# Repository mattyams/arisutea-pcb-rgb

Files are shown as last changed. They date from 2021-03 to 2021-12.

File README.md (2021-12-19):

- [X] Edit QMK firmware for v0.4 Arisutea RGB design (07-07-21)
- [X] v0.4 Arisutea RGB PCBs ordered (07-26-21)
- [X] Assemble v0.4 Arisutea RGB PCB once received (11-21-21)
- [X] Assemble Acrylic Case to v0.4 Arisutea RGB design (11-21-21)

## Arisutea RGB Underglow - Arisu Keyboard PCB with More Modifications...now with MORE!

### Disclaimer: Use these files at your own risk!

アリステア PCB designed using KiCad. The layout was originally created by FateNozomi, inspired by Lyn's EM7 and TGR Alice with some modification. The layout was then modified by CorruptedJef and robotictomato to add USB-C, ESD and to shift/add some keys. This inspired me to modify the layout further by adding the ability to swap your switches out whenever you want, make some keys a little more permenant and add some underglow around the edges. If you notice any issue please open an issue and we can discuss!

Since the layout has been modified yet again I decided to give the project a new name, Arisutea, which translates to Alistair. Obviously keeping the theme running here. 

Check out the iBOM [here](https://htmlpreview.github.io/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)! This was generated with [InteractiveHtmlBom](https://github.com/openscopeproject/InteractiveHtmlBom)!

Key modifications to the PCB:

- Added in Kailh Hotswap sockets.
- Addition of full backspace position, connected to switch 59 (row 0, column 13).
  - Removed switch 63 and repositioned switch 59 to add full backspace position.
- USB-C ESD rework.
- Added 21 SK6812Mini-E underglow LEDs around the edge.
- Added LED indicators for CAPS and NUM lock as well as layer.
- Updated JSON layout file for this particular keyboard.

Renders generated by [Tracespace](https://github.com/tracespace/tracespace).
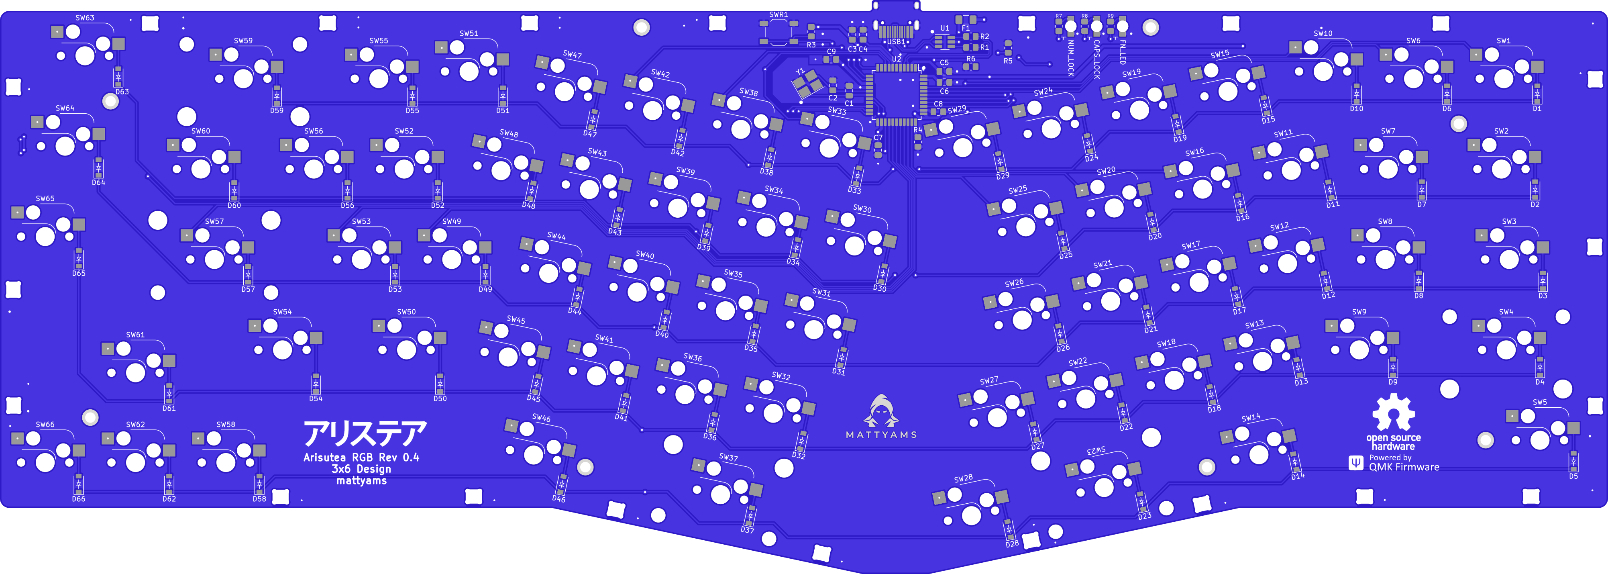
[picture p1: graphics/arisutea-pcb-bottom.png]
Arisutea-RGB

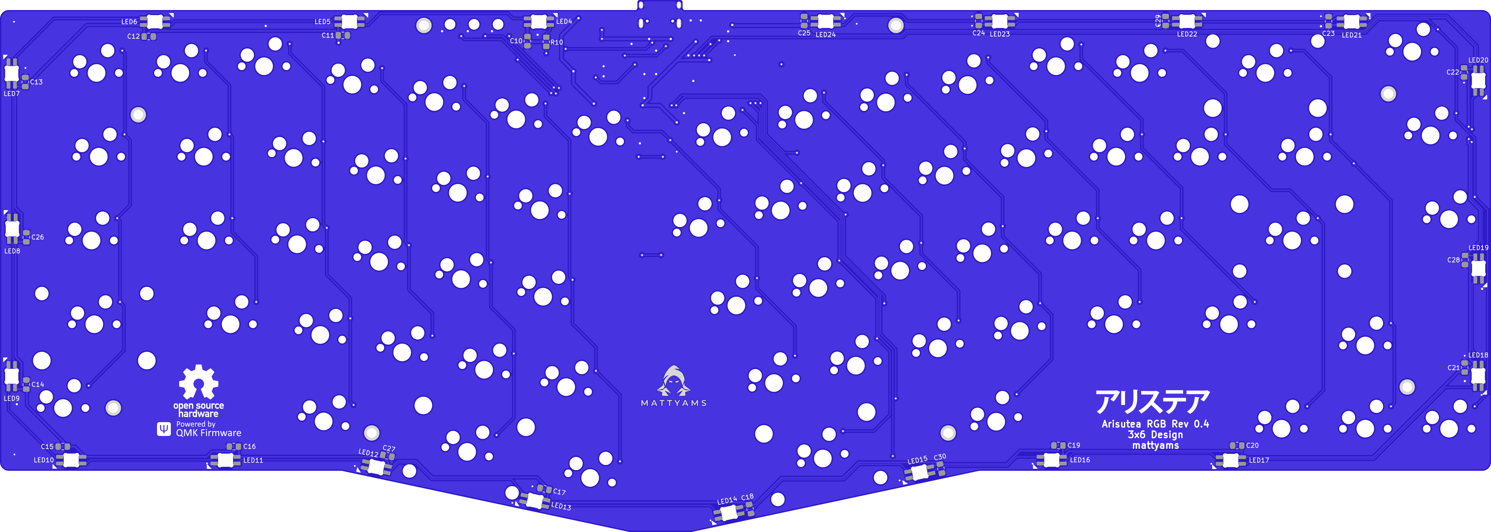
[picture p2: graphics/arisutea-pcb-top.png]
Arisutea-RGB-top

v0.4
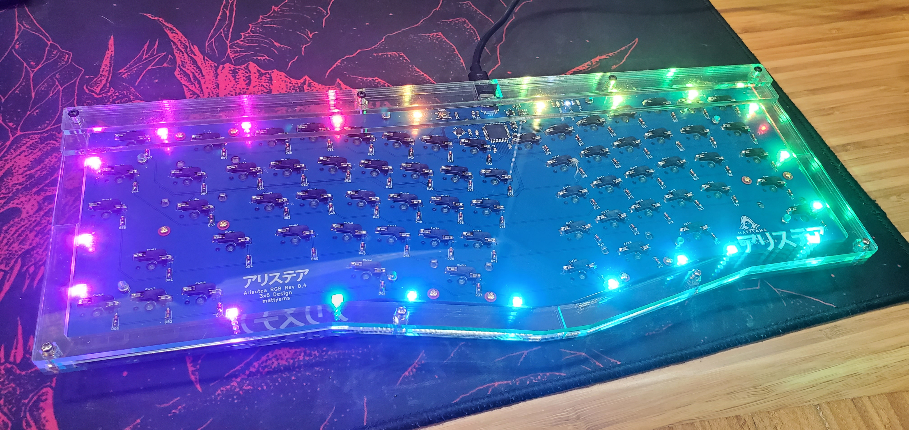
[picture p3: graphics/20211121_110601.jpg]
Arisutea1

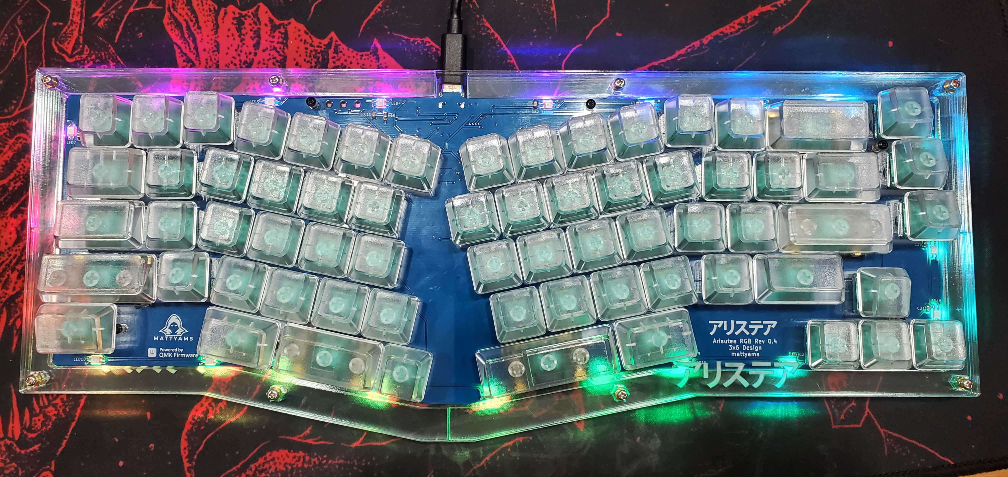
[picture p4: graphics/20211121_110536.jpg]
Arisutea-top1


# QMK Firmware
This can be located in the [firmware](https://github.com/mattyams/arisutea-pcb-rgb/tree/master/firmware) folder. 

# Case Files for Ponoko

Case files are updated to reflect changes to the full backspace on switch 59 and can be found at its repository [arisutea-case](https://github.com/mattyams/arisutea-case).  The most recent case rework works very well with the changes made to the full backspace and addition of the stablizer on the prototypes designed by CorruptedJef and robotictomato. There is now a "boxed" version of the case that is designed to work with some wrist rests that do not have the ortho shape AND case files for version 0.6+ PCBs that include the indicator LEDs.

Ponoko-case-1
Ponoko-case-2
Ponoko-case-3
Ponoko-case-4

# FR4 Plates and Case

Additionaly, there are files for FR4 plates to be made and used with this layout. These can be found at its repository [FR4_Plates](https://github.com/mattyams/arisutea-fr4-plates). The plates are designed to fit with the full backspace and non-stepped capslock. That being said, these will not work on the original Fate Designs PCB. No plans to create plates for the LED indicators on the v0.6+ PCBs. NOTE FOR v0.6.3+ PCBs & RGB! FR4 plates still will work but you will have to drill the holes out manually. If you take this route....go forth cautiously adventurer.

FR4-Plates-1
FR4-Plates-2
FR4-Plates-3
FR4-Plates-6

## Gerber Files

Download the gerber and BOM files under [releases](https://github.com/mattyams/arisutea-pcb-rgb/releases).

## PCB Assembly

SMT/SMD position files are no longer included for any fab house. There have been too many issues with positions wrong, missing parts, etc.

For the components required, you may refer to the bill of materials included along with the release as reference or load up the design file in KiCad.
All the components can be soldered using a regular soldering iron, though soldering the USB-C receptacle might be the biggest hurdle. Adjustments have been made to the USB footprint to allow for a little more error when handsoldering.  Take care when soldering the LEDs to the board, too much heat can destroy the chip.

## Exceprts from original designer, FateNozomi:

Key differences:

- Removed the extra [B] key on the right half and shifted the [NM,.?] row to the left by 0.25U.
- Shifted the 3 keys to the right and added arrow keys.
- Tweaked the bottom so that the 1.5U keys doesn't protrude out a little.

Shifting the [NM,.?] row to the left by 0.25U required quite some work on the arrangement of keys for the right half.
As a result, this does not give the same typing experience as Lyn's EM7 and TGR Alice.
Lyn's EM7 and TGR Alice uses the home row as the center point to vertically align both halves while I used the number row instead.
Due to the nature of staggered keyboards, aligning using the number row resulted in the home row not being aligned.

Disclaimer: Use these files at your own risk.

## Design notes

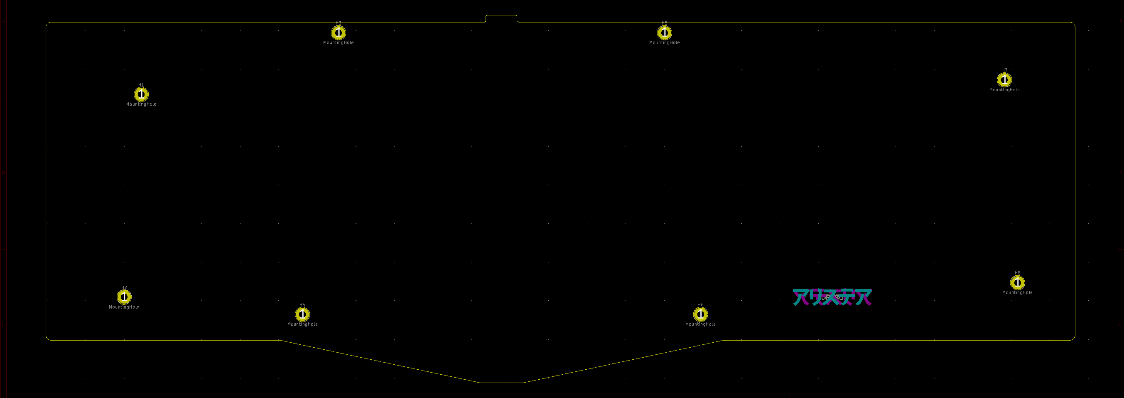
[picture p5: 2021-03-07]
graphics/arisutea-plate-bottom.png

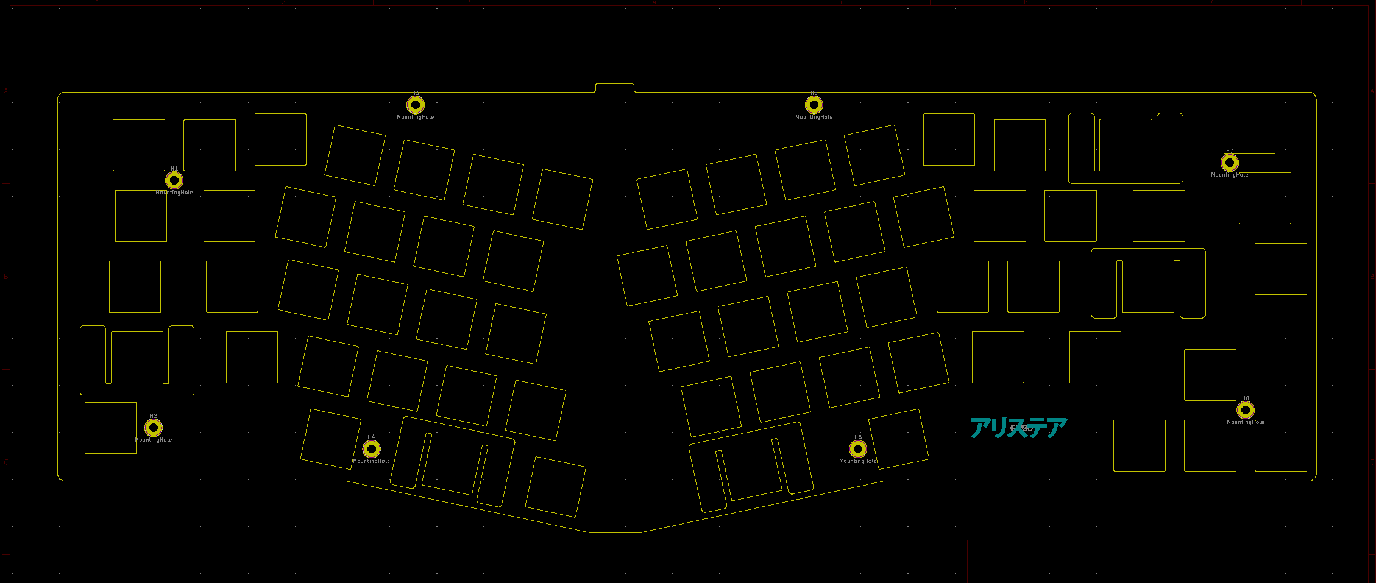
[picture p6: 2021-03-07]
graphics/arisutea-plate-top.png

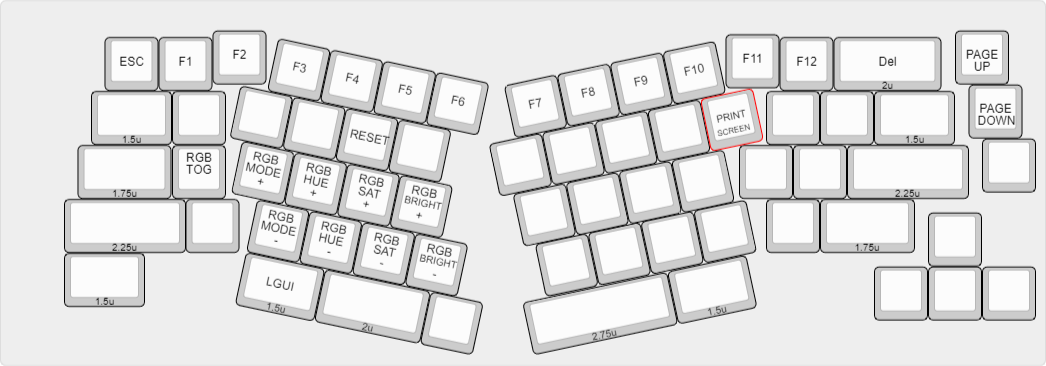
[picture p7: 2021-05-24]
graphics/arisutea---default---layer-1.png

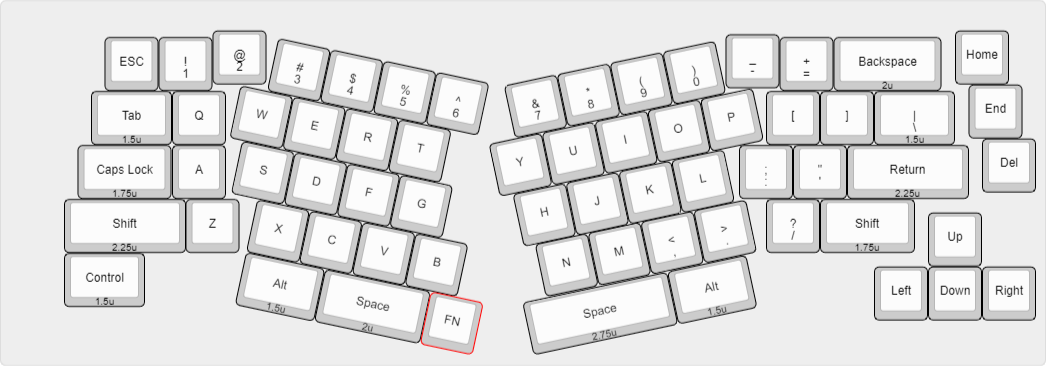
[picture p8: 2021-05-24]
graphics/arisutea---default.png

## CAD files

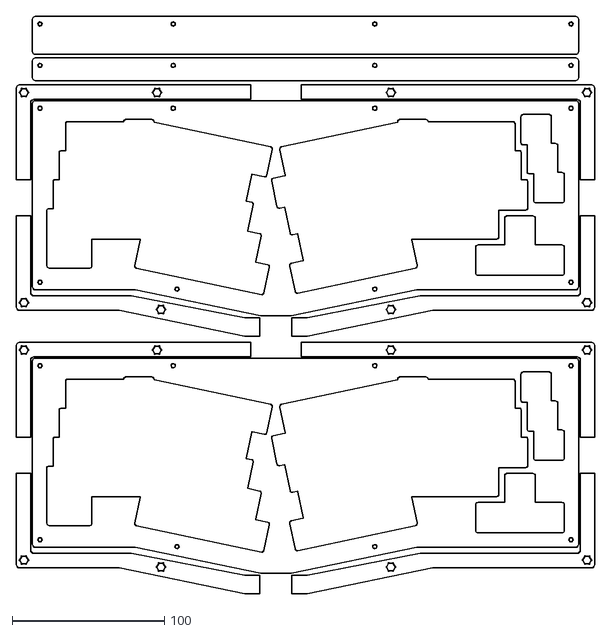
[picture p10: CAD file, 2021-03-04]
hardware/arisutea-case/arisutea_hipro_layer_P2_ponoko.dxf
380.2 x 379.4

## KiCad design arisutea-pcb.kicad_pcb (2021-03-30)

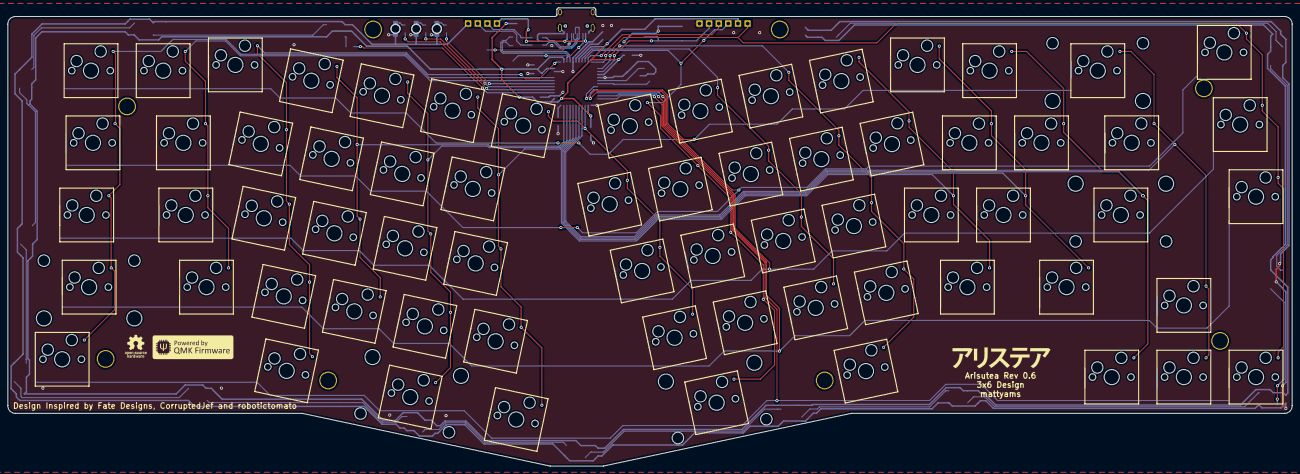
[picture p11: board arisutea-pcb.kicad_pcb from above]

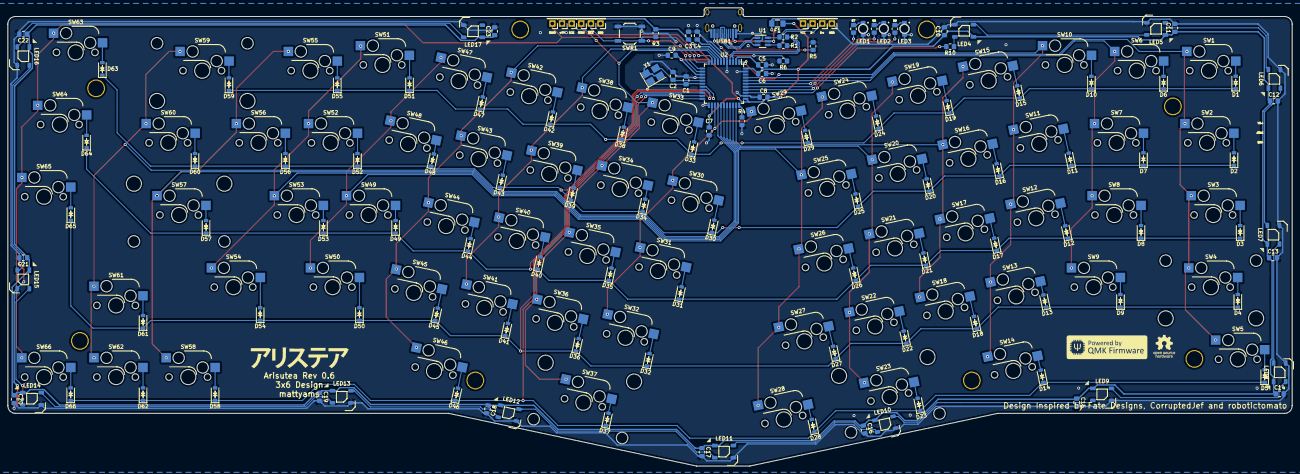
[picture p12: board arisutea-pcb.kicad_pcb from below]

Board: 2 copper layers, 339.1 x 121.0 mm, 212 parts (135 on the bottom side), 124 nets.

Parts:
C1, C2: 22pF; C_0805_2012Metric_Pad1.18x1.45mm_HandSolder
C3: 10uF; C_0805_2012Metric_Pad1.18x1.45mm_HandSolder
C4: 1uF (±10%); C_0805_2012Metric_Pad1.18x1.45mm_HandSolder
C5: 1uF; C_0805_2012Metric_Pad1.18x1.45mm_HandSolder
C6, C7, C8, C9, C10, C11, C12, C13, C14, C15, C16, C17, C18, C19, C20, C21, C22, C23: 0.1uF; C_0805_2012Metric_Pad1.18x1.45mm_HandSolder
D1, D2, D3, D4, D5, D6, D7, D8, D9, D10, D11, D12, D13, D14, D15, D16, D17, D18, D19, D20, D21, D22, D23, D24, D25, D26, D27, D28, D29, D30, D31, D32, D33, D34, D35, D36, D37, D38, D39, D40, D41, D42, D43, D44, D45, D46, D47, D48, D49, D50, D51, D52, D53, D54, D55, D56, D57, D58, D59, D60, D61, D62, D63, D64, D65, D66: D; D_SOD-123
F1: 500mA; Fuse_1206_3216Metric_Pad1.42x1.75mm_HandSolder
H1, H2, H3, H4, H5, H6, H7, H8: ThroughHole; Plated_Through_Hole_M2
J2: MISO; PinHeader_1x01_P2.54mm_Vertical
J3: +5V; PinHeader_1x01_P2.54mm_Vertical
J4: SCK; PinHeader_1x01_P2.54mm_Vertical
J5: MOSI; PinHeader_1x01_P2.54mm_Vertical
J6: ~RES~; PinHeader_1x01_P2.54mm_Vertical
J7, J15: GND; PinHeader_1x01_P2.54mm_Vertical
J12: VCC; PinHeader_1x01_P2.54mm_Vertical
J13: D+; PinHeader_1x01_P2.54mm_Vertical
J14: D-; PinHeader_1x01_P2.54mm_Vertical
LED1: NUM_LOCK; LED_IN-S124ARUW
LED2: CAPS_LOCK; LED_IN-S124ARUW
LED3: FN_LED; LED_IN-S124ARUW
LED4, LED5, LED6, LED7, LED8, LED9, LED10, LED11, LED12, LED13, LED14, LED15, LED16, LED17: WS2812B; LED_WS2812B
LOGO1, LOGO2: arisutea_logo
LOGO3, LOGO4: arisutea_logo; OSHW-Logo_5.7x6mm_SilkScreen
LOGO5: arisutea_logo; QMK_Logo_Dark
LOGO6: QMK_LOGO; QMK_Logo_Dark
R1, R2: 22; R_0805_2012Metric_Pad1.20x1.40mm_HandSolder
R3, R4: 10K; R_0805_2012Metric_Pad1.20x1.40mm_HandSolder
R5, R6: 5k1; R_0805_2012Metric_Pad1.20x1.40mm_HandSolder
R7, R8, R9: 470; R_0805_2012Metric_Pad1.20x1.40mm_HandSolder
R10: 720; R_0805_2012Metric_Pad1.20x1.40mm_HandSolder
SW1, SW6, SW7, SW8, SW9, SW10, SW11, SW12, SW13, SW14, SW15, SW16, SW17, SW18, SW19, SW20, SW21, SW22, SW24, SW25, SW26, SW27, SW28, SW29, SW30, SW31, SW32, SW33, SW34, SW35, SW36, SW38, SW39, SW40, SW41, SW42, SW43, SW44, SW45, SW46, SW47, SW48, SW49, SW50, SW51, SW52, SW53, SW55, SW56, SW58, SW61, SW62, SW63, SW64, SW65, SW66: SW_Push; SW_Hotswap_Kailh_1.00u
SW2, SW5, SW60: SW_Push; SW_Hotswap_Kailh_1.50u
SW3, SW54: SW_Push; SW_Hotswap_Kailh_1.75u
SW4: SW_Push; SW_Hotswap_Kailh_2.25u
SW23: SW_Push; SW_Hotswap_Kailh_2.00u_RevStab
SW37: SW_Push; SW_Hotswap_Kailh_2.75u_RevStab
SW57: SW_Push; SW_Hotswap_Kailh_2.25u_RevStab
SW59: SW_Push; SW_Hotswap_Kailh_2.00u
SWR1: SW_Push; SW_SPST_TL3342
U1: USBLC6-2SC6; SOT-23-6_Handsoldering
U2: ATmega32U4-AU; TQFP-44_10x10mm_P0.8mm
USB1: USB_C_HRO_TYPE-C-31-M-12-USB_Type-C; USB_C_Receptacle_HRO_TYPE-C-31-M-12-HandSoldering
Y1: Crystal_GND24; Crystal_SMD_TXC_7M-4Pin_3.2x2.5mm_HandSoldering

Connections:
+5V: C3.1, C5.1, C6.1, C7.1, C8.1, C9.1, C10.1, C11.1, C12.1, C13.1, C14.1, C15.1, C16.1, C17.1, C18.1, C19.1, C20.1, C21.1, C22.1, C23.1, F1.1, J3.1, LED4.1, LED5.1, LED6.1, LED7.1, LED8.1, LED9.1, LED10.1, LED11.1, LED12.1, LED13.1, LED14.1, LED15.1, LED16.1, LED17.1, R3.1, U2.2, U2.7, U2.14, U2.24, U2.34, U2.44
/MISO: J2.1, SW63.2, SW64.2, SW65.2, SW66.2, U2.11
/MOSI: J5.1, U2.10
/SCK: J4.1, SW33.2, SW34.2, SW35.2, SW36.2, SW37.2, U2.9
/col0: SW1.2, SW2.2, SW3.2, SW4.2, SW5.2, U2.41
/col1: SW6.2, SW7.2, SW8.2, SW9.2, U2.40
/col2: SW10.2, SW11.2, SW12.2, SW13.2, SW14.2, U2.1
/col3: SW15.2, SW16.2, SW17.2, SW18.2, U2.32
/col4: SW19.2, SW20.2, SW21.2, SW22.2, SW23.2, U2.31
/col5: SW24.2, SW25.2, SW26.2, SW27.2, SW28.2, U2.30
/col6: SW29.2, SW30.2, SW31.2, SW32.2, U2.25
/col8: SW38.2, SW39.2, SW40.2, SW41.2, U2.8
/col9: SW42.2, SW43.2, SW44.2, SW45.2, SW46.2, U2.12
/col10: SW47.2, SW48.2, SW49.2, SW50.2, U2.29
/col11: SW51.2, SW52.2, SW53.2, SW54.2, U2.28
/col12: SW55.2, SW56.2, SW57.2, SW58.2, U2.27
/col13: SW59.2, SW60.2, SW61.2, SW62.2, U2.26
/row0: D1.1, D6.1, D10.1, D15.1, D19.1, D24.1, D29.1, D33.1, D38.1, D42.1, D47.1, D51.1, D55.1, D59.1, U2.18
/row1: D2.1, D7.1, D11.1, D16.1, D20.1, D25.1, D30.1, D34.1, D39.1, D43.1, D48.1, D52.1, D56.1, D60.1, D63.1, U2.19
/row2: D3.1, D8.1, D12.1, D17.1, D21.1, D26.1, D31.1, D35.1, D40.1, D44.1, D49.1, D53.1, D57.1, D64.1, U2.20
/row3: D4.1, D9.1, D13.1, D18.1, D22.1, D27.1, D32.1, D36.1, D41.1, D45.1, D50.1, D54.1, D61.1, D65.1, U2.21
/row4: D5.1, D14.1, D23.1, D28.1, D37.1, D46.1, D58.1, D62.1, D66.1, U2.22
/~RES~: J6.1, R3.2, SWR1.2, U2.13
CAPS_L: R8.2, U2.38
D+: R1.1, U2.4
D-: R2.1, U2.3
FN_L: R7.2, U2.39
GND: C1.1, C2.2, C3.2, C4.2, C5.2, C6.2, C7.2, C8.2, C9.2, C10.2, C11.2, C12.2, C13.2, C14.2, C15.2, C16.2, C17.2, C18.2, C19.2, C20.2, C21.2, C22.2, C23.2, J7.1, J15.1, LED1.C, LED2.C, LED3.C, LED4.3, LED5.3, LED6.3, LED7.3, LED8.3, LED9.3, LED10.3, LED11.3, LED12.3, LED13.3, LED14.3, LED15.3, LED16.3, LED17.3, R4.2, R5.2, R6.2, SWR1.1, U1.2, U2.5, U2.15, U2.23, U2.35, U2.43, USB1.A1, USB1.A12, USB1.S1, Y1.2, Y1.4
NUM_L: R9.2, U2.37
unnamed: C4.1, U2.6
unnamed: D1.2, SW1.1
unnamed: D2.2, SW2.1
unnamed: D3.2, SW3.1
unnamed: D4.2, SW4.1
unnamed: D5.2, SW5.1
unnamed: D6.2, SW6.1
unnamed: D7.2, SW7.1
unnamed: D8.2, SW8.1
unnamed: D9.2, SW9.1
unnamed: D10.2, SW10.1
unnamed: D11.2, SW11.1
unnamed: D12.2, SW12.1
unnamed: D13.2, SW13.1
unnamed: D14.2, SW14.1
unnamed: D15.2, SW15.1
unnamed: D16.2, SW16.1
unnamed: D17.2, SW17.1
unnamed: D18.2, SW18.1
unnamed: D19.2, SW19.1
unnamed: D20.2, SW20.1
unnamed: D21.2, SW21.1
unnamed: D22.2, SW22.1
unnamed: D23.2, SW23.1
unnamed: D24.2, SW24.1
unnamed: D25.2, SW25.1
unnamed: D26.2, SW26.1
unnamed: D27.2, SW27.1
unnamed: D28.2, SW28.1
unnamed: D29.2, SW29.1
unnamed: D30.2, SW30.1
unnamed: D31.2, SW31.1
unnamed: D32.2, SW32.1
unnamed: D33.2, SW33.1
unnamed: D34.2, SW34.1
unnamed: D35.2, SW35.1
unnamed: D36.2, SW36.1
unnamed: D37.2, SW37.1
unnamed: D38.2, SW38.1
unnamed: D39.2, SW39.1
unnamed: D40.2, SW40.1
unnamed: D41.2, SW41.1
unnamed: D42.2, SW42.1
unnamed: D43.2, SW43.1
unnamed: D44.2, SW44.1
unnamed: D45.2, SW45.1
unnamed: D46.2, SW46.1
unnamed: D47.2, SW47.1
unnamed: D48.2, SW48.1
unnamed: D49.2, SW49.1
unnamed: D50.2, SW50.1
unnamed: D51.2, SW51.1
unnamed: D52.2, SW52.1
unnamed: D53.2, SW53.1
unnamed: D54.2, SW54.1
unnamed: D55.2, SW55.1
unnamed: D56.2, SW56.1
unnamed: D57.2, SW57.1
unnamed: D58.2, SW58.1
unnamed: D59.2, SW59.1
unnamed: D60.2, SW60.1
unnamed: D61.2, SW61.1
unnamed: D62.2, SW62.1
unnamed: D63.2, SW63.1
unnamed: D64.2, SW64.1
unnamed: D65.2, SW65.1
unnamed: D66.2, SW66.1
unnamed: J13.1, R1.2, U1.4
unnamed: J14.1, R2.2, U1.6
unnamed: LED1.A, R7.1
unnamed: LED2.A, R8.1
unnamed: LED3.A, R9.1
unnamed: LED4.2, LED5.4
unnamed: LED4.4, R10.1
unnamed: LED5.2, LED6.4
unnamed: LED6.2, LED7.4
unnamed: LED7.2, LED8.4
unnamed: LED8.2, LED9.4
unnamed: LED10.2, LED11.4
unnamed: LED9.2, LED10.4
unnamed: LED11.2, LED12.4
unnamed: LED12.2, LED13.4
unnamed: LED13.2, LED14.4
unnamed: LED14.2, LED15.4
unnamed: LED15.2, LED16.4
unnamed: LED16.2, LED17.4
unnamed: R4.1, U2.33
unnamed: R5.1, USB1.A5
unnamed: R6.1, USB1.B5
unnamed: U1.1, USB1.A7, USB1.B7
unnamed: U1.3, USB1.A6, USB1.B6
RGB: R10.2, U2.36
VCC: F1.2, J12.1, U1.5, USB1.A4, USB1.A9
XTAL1: C1.2, U2.17, Y1.1
XTAL2: C2.1, U2.16, Y1.3

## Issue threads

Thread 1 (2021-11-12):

It's tested? It works?

DLopezGo90, 2021-11-12:
Hi bro, I'm considering building this keyboard

It's tested right?

mattyams, 2021-11-12:
v0.3 has been tested and working great. I have v0.4 sitting here but real life got in the way and I wasn't able to build it, I will soon. There is no reason v0.4 shouldn't work as I only added a few more LEDs to the edge in that version.

DLopezGo90, 2021-11-14:
Hey bro I want my build to look like this:

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

I want to build it only using frosted acrylic plates. I was thinking about doing something like this:

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

What do you think about this?

mattyams, 2021-11-14:
Should work out fine. I have a similar build that I did but not with this particular PCB and opal acrylic instead of frosted. See attached:
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

DLopezGo90, 2021-11-17:
Hey bro how many acrylic plates are part of that case? 3 or 4?

mattyams, 2021-11-17:
In the one pictured there are 22 pieces total. This is because the parts for the inner case are broken out to 4 pieces to keep plastic waste to a minimum.

Closed 2021-11-21.

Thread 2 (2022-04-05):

help adding additional 3 key to the left side for symmetric and flex cut to pcb

xshadowlegendx, 2022-04-05:
hello, I want an alice keyboard with arrow key like this arisu one but also love to have it to be symmetric and flex cut to have it build with gasket mount case for extra softness or flex, but I do not know how to design a pcb and could not find layout that I want like the image attached below and with flex cut, so could you maybe help adding 3 key to the left so that it look symmetric like the image and some flex cuts?

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

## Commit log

2021-03-04 USB-C, hotswaps, ESD update, plates, so much
    Added USB-C, updated case files, ESD rework, FR4 plates made, name change, hotswap sockets, route rework
    [Arisutea_FR4_Plate_Bottom.kicad_pcb, Arisutea_FR4_Plate_Top.kicad_pcb, arisu.kicad_pcb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]
2021-03-04 Delete diode_position.txt
    not needed
2021-03-07 routing rework, mounting holes changed, add power LED, crystal adjustment
    Moved some routes around...again. Changed the mounting holes to through holes for plate mounting. Added a power LED, because why not? Adjusted the crystal placement.
    [arisutea-pcb.kicad_pcb, arisutea-pcb.sch, matrix.sch]
2021-03-07 adjusted mask, added gerbers
    [arisutea-pcb.kicad_pcb]
2021-03-07 fixed silly routing mistake
    [arisutea-pcb.kicad_pcb]
2021-03-07 house keeping, fixed another silly routing mistake, regen gerbs and BOM
    [Arisutea_FR4_Plate_Bottom.kicad_pcb, Arisutea_FR4_Plate_Top.kicad_pcb, arisu_hipro_layer_P2_ponoko.dxf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]
2021-03-07 update name
    [arisutea_hipro_layer_P2_ponoko.dxf, arisutea_lopro_case_P2_ponoko_backspace_comp.dxf]
2021-03-07 add kicad images for plates
2021-03-07 update case files for matte option, update readmes
2021-03-08 footprint and trace cleanup
    Changed some footprints to show clearer positioning of U1, U2 and Y1 as well as all the key switch diodes on the silkscreen.
    Correct footprint and name for LED.
    Moved a couple of traces around slightly for aesthetics.
    Removed some trace tails that were just hanging out.
    [arisutea-pcb.kicad_pcb, arisutea-pcb.sch]
2021-03-10 update readme to add FR4 plate pics
2021-03-12 fix some routing boo boos and added boxed case design
    [arisutea-pcb.kicad_pcb, arisutea_hipro_case_P2_boxed_F360.dxf, arisutea_lopro_case_P2_boxed_F360.dxf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]
2021-03-12 updated gerbies
    [arisutea-pcb.kicad_pcb]
2021-03-14 FR4 plate assembly and case update
    [arisutea_hipro_case_P2_boxed_F360.dxf, arisutea_lopro_case_P2_boxed_F360.dxf, arisutea_lopro_case_P2_ponoko_backspace_comp.dxf]
2021-03-16 update photos
    [arisutea-pcb.kicad_pcb]
2021-03-21 versioning to 0.4
    remove LED...../sigh
    [arisutea-pcb.kicad_pcb, arisutea-pcb.sch, matrix.sch]
2021-03-21 update switch positions to be more uniform
    [arisutea-pcb.kicad_pcb]
2021-03-22 BOM and position files update
2021-03-23 library, silkscreen and gerber update
    I moved all the footprints into a single library so that if folks don't have the particular lib they won't have to go and search for it or try to replace. Silkscreen was updated again to show clearer positioning of components and gerbers updated to most recent. Version number isn't changing as no big updates were made.
    [arisutea-pcb.kicad_pcb, arisutea-pcb.sch, arisutea_logo v1.dxf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]
2021-03-24 footprint and 3d model updates
    [arisutea-pcb.kicad_pcb]
2021-03-25 0.5 update
    Fixes some routing that really did not need to be fixed but my OCD was screaming at me. Fixes an issue with the USB port only being shown as a through hole component and not an SMD. Reup gerbies, BOM and POS files.
    [arisutea-pcb.kicad_pcb, arisutea-pcb.sch, matrix.sch]
2021-03-27 added LED strip and indicator support, new cases for indicators
    [arisutea-pcb.kicad_pcb, arisutea-pcb.sch, matrix.sch]
2021-03-29 add firmware files
    [arisutea-pcb.sch]
2021-03-30 WS2812 PADS ADDED
    [arisutea-pcb.kicad_pcb, arisutea-pcb.sch, matrix-rgb.sch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]
2021-05-24 Rev 0.2
    Changed LEDs to SK6812Mini-E and rerouted.
    [arisutea-pcb.kicad_sch, arisutea-pcb.sch, matrix-rgb.kicad_sch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]
2021-06-19 Rev 0.3
    Might send this one out to get made. Not sure yet.
    - Added 2 more LEDs to the edge and positioned them to be a little more evenly spread out.
    - Rerouted all LED traces for better aesthetics and functionality.
    - Increased power trace size. This might not be needed but it can't hurt to add with the addition of the LEDs.
    - Removed programming headers. This was a personal decision as I never used them or found a need for them. It helped free up some space to route LEDs.
    - Updated library, images, gerbies and BOM.
    - Added a firmware that has not been tested yet, but should work in theory.
    - No more position files. Too many issues at various fab houses with positions/parts/QA with previou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
    [arisutea-pcb.kicad_sch, matrix-rgb.kicad_sch, matrix.kicad_sch]
2021-07-09 smol update
    [arisutea-pcb.kicad_sch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]
2021-07-23 added MOAR LEDZZZZZZZZZ
    5 more to be exact.
    [arisutea-pcb.kicad_sch, matrix-rgb.kicad_sch, matrix.kicad_sch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]
2021-07-25 added different logo, redid gerbies
    [arisutea-pcb-B_Cu.gbl, arisutea-pcb-B_Mask.gbs, arisutea-pcb-B_Paste.gbp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]
2021-08-11 Rev 0.4
    Added more LEDs, moved some traces around, updated iBOM, added new renders...and things
    [arisutea-pcb.kicad_sch]
2021-08-11 Removed arisutea-case and FR4_plates to replace with submodule
    [Arisutea_FR4_Plate_Bottom.kicad_pcb, Arisutea_FR4_Plate_Top.kicad_pcb]
2021-08-11 Replaced case and fr4-plates directory with submodules
2021-08-11 remove plate gerbers
    These can be found in the plates subfolder gerber folder now.
    [arisutea-pcb-B_Cu.gbl, arisutea-pcb-B_Mask.gbs, arisutea-pcb-B_Paste.gbp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]
2021-08-11 Update arisutea-fr4-plates
2021-12-20 Kicad version bump
